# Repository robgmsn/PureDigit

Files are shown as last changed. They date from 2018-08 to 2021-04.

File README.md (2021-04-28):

# GMSN! Pure Digit
  
cc-by 4.0

Rob Spencer

[gmsn.co.uk](https://gmsn.co.uk)

[forum.gmsn.co.uk](https://forum.gmsn.co.uk)

Open Source Synth Designs.

DESIGN STATUS: Awaiting Testing - Ready for beta testing

Digit Updated to V2.0 28/4/21

RC filter added to DAC output.
Cap added to output opamp.
SD Card Reader added.

To do: Replace power so 5V comes from case power supply, inline with low noise techniques. May require complete redesign.

### Intro
This repo contains both the Library and Sketches for the GMSN! Pure Digit.

A small programmable utility module which accepts +/- 10V in,
does some digital processing, and outputs a +/-10V signal.

It has a 2 Channel 12bit ADC In, 12bit DAC Out, a 24
position rotary encoder with switch and a 7 segment LED display.

## To install the library

The library is installed via the normal Arduino Library management system.
  
1. From within the Arduino IDE, click on Sketch>Include Library>Manage Libraries...
  
2. Search for "GMSN" and click install.

### Sketches   
- [x] VCO
- [x] Noise
- [x] EmptySketch
- [x] RandomSequencer
- [ ] Clock Divider
- [ ] MicroTuner
- [x] BitCrusher
- [ ] Drums
- [ ] RhythmPlayer
- [ ] SwingMachine
- [ ] LFO
- [ ] StepLFO
- [x] DCLevel
- [ ] Module Testing Functions
- [ ] FrequencyCounter
- [ ] DCMeter

### Methods

encodeVal(int value) - Call this to increment or decrement a value with the rotary encoder.

displayLED(int digit, byte mode, bool dp) - The display has two modes:
                              1) Standard 0 - 9 digital digit.
                              2) Positional representation with 12 values. Where the knob is pointing!
                                 This uses the result of a modulo calculation so the value can be greater
                                 than 12 and it will keep rotating. It can't go less than zero though.

displayOff() - Turns the display off.

dacWrite(int value) - Write a value to the DAC. Yes, it's got a 20V P2P voltage!! :D
           0    =   +10V
           2048 =   0V
           4095 =   -10V

dacWriteCal(int value) - Write a value to the DAC, but using the calibration values. Use this when you need to ensure the output matches the module input, especially when processing audio or pitch CV.

adcRead(byte channel) - Read a 20V P2P from the DAC, channel 1 or 2. Voltages as above.

dontCalibrate() - If you don't actually need to use dacWriteCal(), then call dontCalibrate() before begin().

calibrate() - Some applications need the output to follow the output as closely as possible. If you have an audio signal coming in, you want the output to be the same. Due small differences in components, there will be both Gain Error and Offset Error that needs to be accounted for. This is a very simple routine which runs once everytime the module is flashed. The calibration values are then stored in EEPROM and used whenever dacWriteCal() is called.

getSwitchState() - This method returns the state of the switch, 1 for pressed, 0 for not pressed.

### How to calibrate

If the module hasn't been calibrated, it will run through a self calibration routine. You just need a single patch cable, no other modules or test kit required!

First of all the module will flash "8" a few times, before entering the calibration routine.

1) When it displays "1" patch from the output back into input 1.
2) Long Press the encoder.
3) Patch from output into input 2.
4) Long Press the encoder.

It will then count down to zero and flash. The module is now calibrated.

N.B. The calibration settings are stored in EEPROM, which is overwritten every time the module is flashed, therefor the calibration routing will run everytime the module is flashed.

### Example Sketch
```
// A random sequencer with variable delay

#include <Digit.h>                    //Include the Digit library

Digit digit;                          //Create a Digit called digit. This object now has the methods above available to it.

//Setup variables
int encPos = 1;                       //Just some variables for us to use in the code

void setup() {
 digit.begin();                       //Tell digit to configure its self.
}

void loop() {
   encPos = digit.encodeVal(encPos);  //Increment or decrement the varible encPos
   digit.displayLED(encPos, 2, 0);    //Display the value of encPos as a Positional Representation with no decimal point
   digit.dacWrite(random(4095));      //Output a random value between 0 and 4095, which is analogue +/- 10V
   delay(encPos);                     //Delay for encPos milliseconds.
}
```

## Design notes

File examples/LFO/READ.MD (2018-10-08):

LFO 
This code by Andy Cobley
Rate is controlled by CV1, Shape by CV2. The shape changes the duty cycle, for a Square wave this gives PWM, Triangle from +saw to triangle to -Saw. There others similarly.

Encoder position

0: Sine
1: Square
2: Triangle
3: Sine based on Triangle (can produce a nice output)

4,5,6,7 the same but slower cycles
Higher encoder positons give slower cycles still .
Loops at 19 and 0

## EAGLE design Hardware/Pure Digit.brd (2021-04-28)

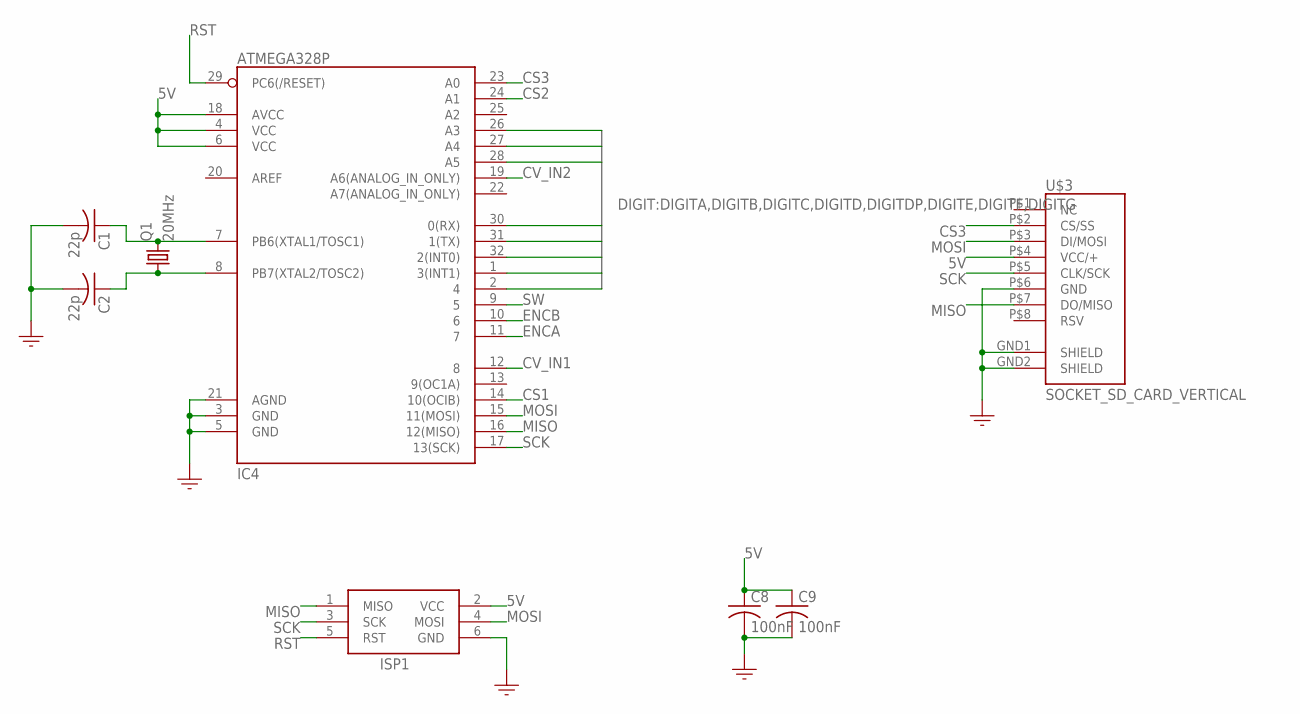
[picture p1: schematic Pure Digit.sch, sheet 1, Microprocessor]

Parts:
C1, C2: 22p; C0805
C8, C9: 100nF; C0805
IC4: ATMEGA328P; TQFP32-08
ISP1: HEADER2X3-6; AVRISP
Q1: 20MHz; SM49
U$3: SOCKET_SD_CARD_VERTICAL; PJS008U-3000

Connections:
5V: C8.1, C9.1, IC4.4 (VCC), IC4.6 (VCC), IC4.18 (AVCC), ISP1.2 (VCC), U$3.P$4 (VCC/+); also elsewhere on the board
CS1: IC4.14 (10(OCIB)); also elsewhere on the board
CS2: IC4.24 (A1); also elsewhere on the board
CS3: IC4.23 (A0), U$3.P$2 (CS/SS)
CV_IN1: IC4.12 (8); also elsewhere on the board
CV_IN2: IC4.19 (A6(ANALOG_IN_ONLY)); also elsewhere on the board
DIGITA: IC4.30 (0(RX)); also elsewhere on the board
DIGITB: IC4.28 (A5); also elsewhere on the board
DIGITC: IC4.27 (A4); also elsewhere on the board
DIGITD: IC4.26 (A3); also elsewhere on the board
DIGITDP: IC4.1 (3(INT1)); also elsewhere on the board
DIGITE: IC4.2 (4); also elsewhere on the board
DIGITF: IC4.32 (2(INT0)); also elsewhere on the board
DIGITG: IC4.31 (1(TX)); also elsewhere on the board
ENCA: IC4.11 (7); also elsewhere on the board
ENCB: IC4.10 (6); also elsewhere on the board
GND: C1.2, C2.2, C8.2, C9.2, IC4.3 (GND), IC4.5 (GND), IC4.21 (AGND), ISP1.6 (GND), U$3.GND1 (SHIELD), U$3.GND2 (SHIELD), U$3.P$6 (GND); also elsewhere on the board
MISO: IC4.16 (12(MISO)), ISP1.1 (MISO), U$3.P$7 (DO/MISO); also elsewhere on the board
MOSI: IC4.15 (11(MOSI)), ISP1.4 (MOSI), U$3.P$3 (DI/MOSI); also elsewhere on the board
unnamed: C1.1, IC4.7 (PB6(XTAL1/TOSC1)), Q1.2
unnamed: C2.1, IC4.8 (PB7(XTAL2/TOSC2)), Q1.1
RST: IC4.29 (PC6(/RESET)), ISP1.5 (RST)
SCK: IC4.17 (13(SCK)), ISP1.3 (SCK), U$3.P$5 (CLK/SCK); also elsewhere on the board
SW: IC4.9 (5); also elsewhere on the board

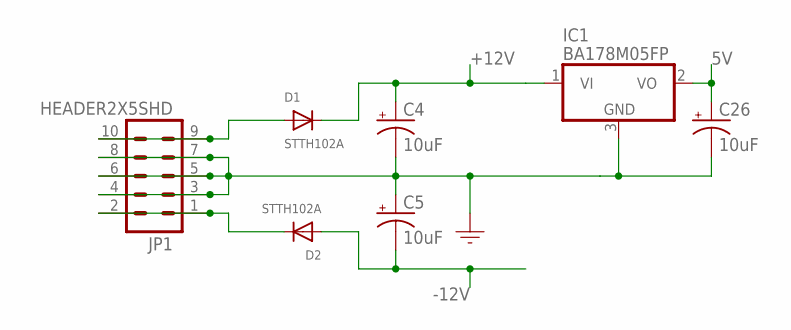
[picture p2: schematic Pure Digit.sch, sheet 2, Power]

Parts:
C4, C5, C26: 10uF; 153CLV-0505
D1, D2: STTH102A; SMADIODE
IC1: BA178M05FP; TO252
JP1: HEADER2X5SHD; 2X5-SHROUDED

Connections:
5V: C26.+, IC1.2 (VO); also elsewhere on the board
+12V: C4.+, D1.C, IC1.1 (VI); also elsewhere on the board
-12V: C5.-, D2.A; also elsewhere on the board
GND: C4.-, C5.+, C26.-, IC1.3 (GND), JP1.3, JP1.4, JP1.5, JP1.6, JP1.7, JP1.8; also elsewhere on the board
unnamed: D1.A, JP1.9, JP1.10
unnamed: D2.C, JP1.1, JP1.2

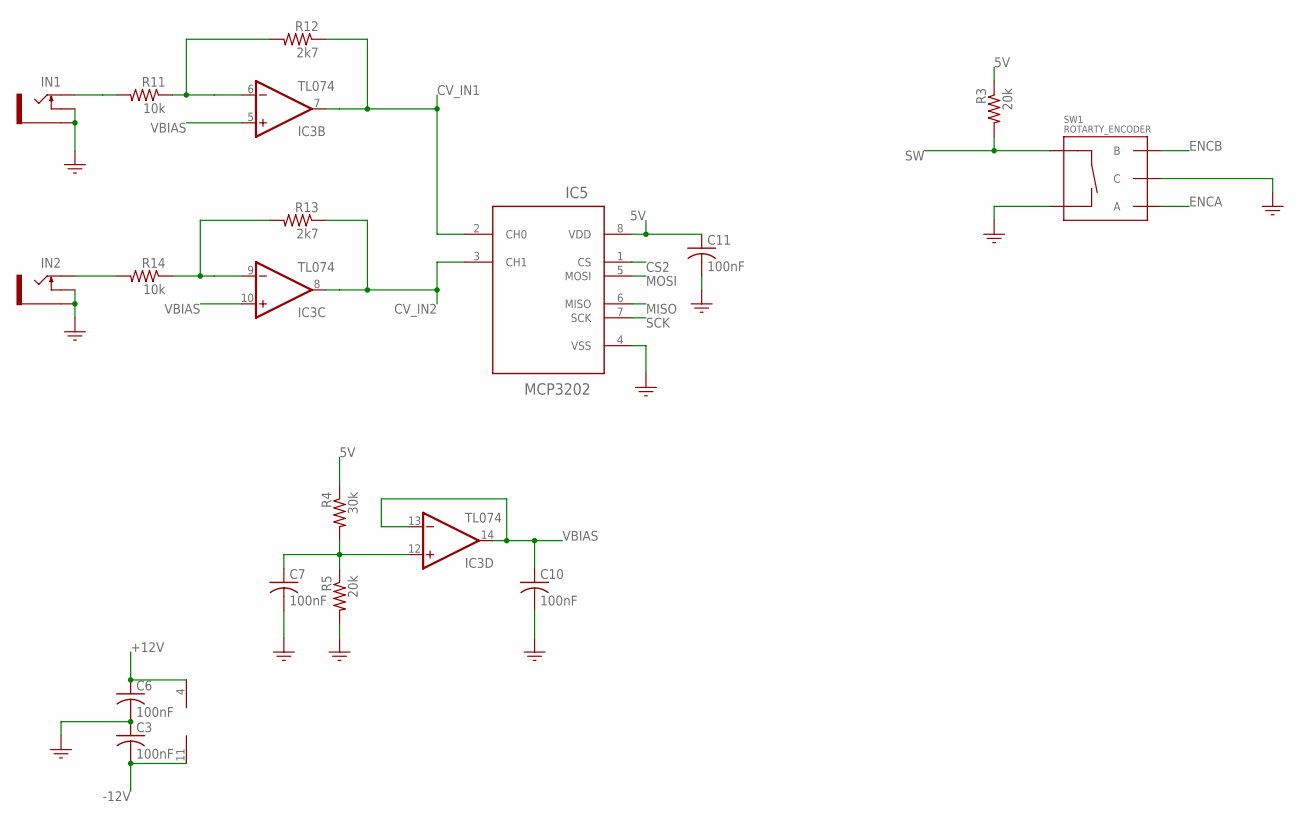
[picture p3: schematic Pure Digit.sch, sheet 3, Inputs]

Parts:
C3, C6, C7, C10, C11: 100nF; C0805
IC3: TL074; SO14
IC5: MCP3202; SOIC--8
IN1, IN2: PJ301M-12
R3, R5: 20k; R0805
R4: 30k; R0805
R11, R14: 10k; R0805
R12, R13: 2k7; R0805
SW1: ROTARTY_ENCODER; ROTARY_ENC_PLAIN

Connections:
5V: C11.1, IC5.8 (VDD), R3.1, R4.1; also elsewhere on the board
+12V: C6.1, IC3.4 (V+); also elsewhere on the board
-12V: C3.2, IC3.11 (V-); also elsewhere on the board
CS2: IC5.1 (CS); also elsewhere on the board
CV_IN1: IC3.7 (OUT), IC5.2 (CH0), R12.1; also elsewhere on the board
CV_IN2: IC3.8 (OUT), IC5.3 (CH1), R13.1; also elsewhere on the board
ENCA: SW1.A; also elsewhere on the board
ENCB: SW1.B; also elsewhere on the board
GND: C3.1, C6.2, C7.2, C10.2, C11.2, IC5.4 (VSS), IN1.GND (SLEEVE), IN1.NORM (SWITCH), IN2.GND (SLEEVE), IN2.NORM (SWITCH), R5.2, SW1.C, SW1.SW-; also elsewhere on the board
MISO: IC5.6 (MISO); also elsewhere on the board
MOSI: IC5.5 (MOSI); also elsewhere on the board
unnamed: IN1.TIP, R11.2
unnamed: IN2.TIP, R14.2
unnamed: C7.1, IC3.12 (+IN), R4.2, R5.1
unnamed: IC3.6 (-IN), R11.1, R12.2
unnamed: IC3.9 (-IN), R13.2, R14.1
SCK: IC5.7 (SCK); also elsewhere on the board
SW: R3.2, SW1.SW+; also elsewhere on the board
VBIAS: C10.1, IC3.5 (+IN), IC3.10 (+IN), IC3.13 (-IN), IC3.14 (OUT)

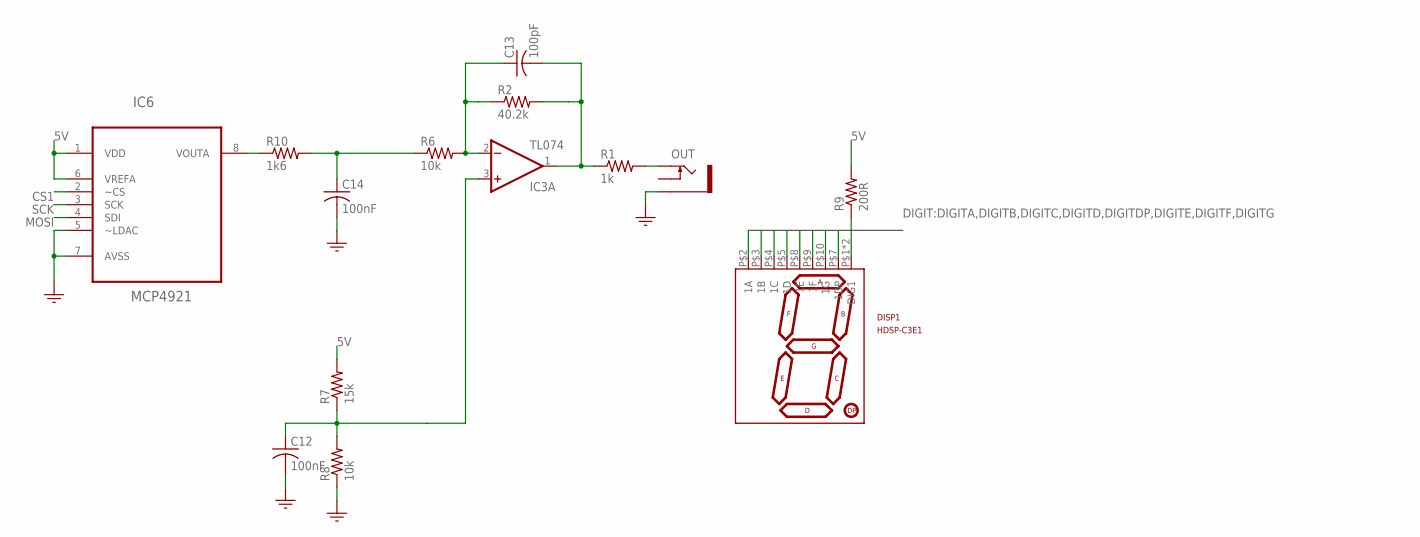
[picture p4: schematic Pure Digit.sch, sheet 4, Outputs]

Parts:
C12, C14: 100nF; C0805
C13: 100pF; C0805
DISP1: HDSP-C3E1; 7-SEGMENT-1DIGIT
IC3: TL074; SO14
IC6: MCP4921; SOIC8
OUT: PJ301M-12
R1: 1k; R0805
R2: 40.2k; R0805
R6, R8: 10k; R0805
R7: 15k; R0805
R9: 200R; R0805
R10: 1k6; R0805

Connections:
5V: IC6.1 (VDD), IC6.6 (VREFA), R7.2, R9.2; also elsewhere on the board
CS1: IC6.2 (~CS); also elsewhere on the board
DIGITA: DISP1.P$2 (1A); also elsewhere on the board
DIGITB: DISP1.P$3 (1B); also elsewhere on the board
DIGITC: DISP1.P$4 (1C); also elsewhere on the board
DIGITD: DISP1.P$5 (1D); also elsewhere on the board
DIGITDP: DISP1.P$7 (1DP); also elsewhere on the board
DIGITE: DISP1.P$8 (1E); also elsewhere on the board
DIGITF: DISP1.P$9 (1F); also elsewhere on the board
DIGITG: DISP1.P$10 (1G); also elsewhere on the board
GND: C12.2, C14.2, IC6.5 (~LDAC), IC6.7 (AVSS), OUT.GND (SLEEVE), R8.1; also elsewhere on the board
MOSI: IC6.4 (SDI); also elsewhere on the board
unnamed: C12.1, IC3.3 (+IN), R7.1, R8.2
unnamed: C13.2, IC3.1 (OUT), R1.1, R2.2
unnamed: OUT.TIP, R1.2
unnamed: C14.1, R6.1, R10.2
unnamed: C13.1, IC3.2 (-IN), R2.1, R6.2
unnamed: DISP1.P$1 (DIG1), DISP1.P$6 (DIG1), R9.1
unnamed: IC6.8 (VOUTA), R10.1
SCK: IC6.3 (SCK); also elsewhere on the board

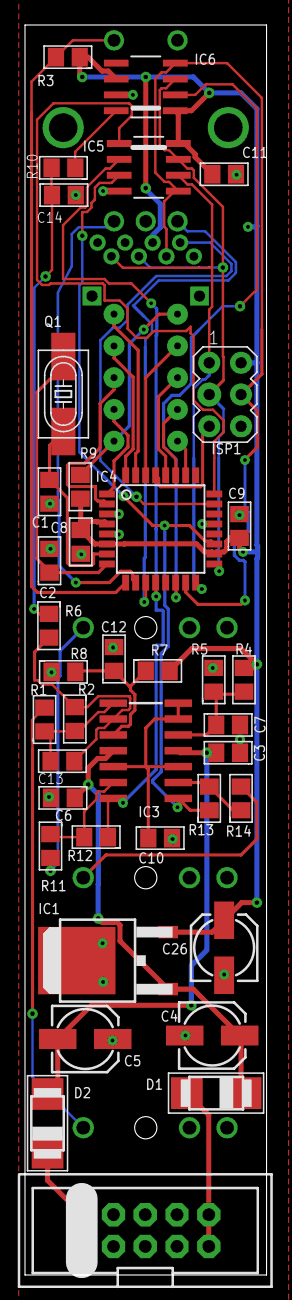
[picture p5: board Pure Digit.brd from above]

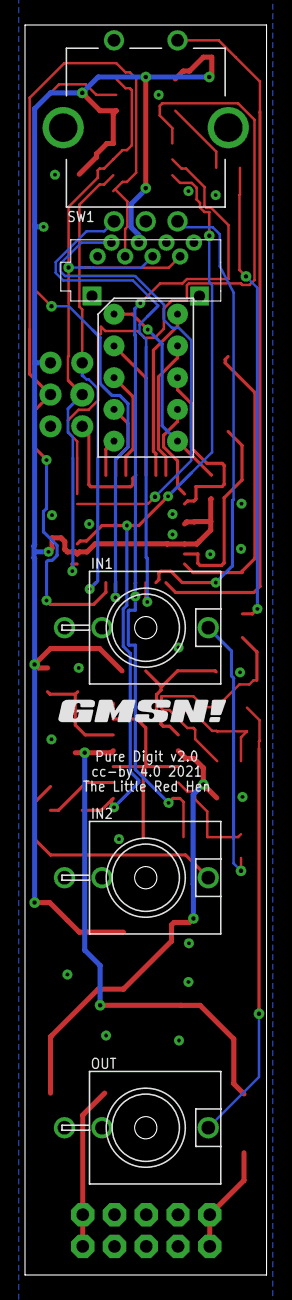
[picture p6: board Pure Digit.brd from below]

Board: 2 copper layers, 19.3 x 100.0 mm, 46 parts (7 on the bottom side), 41 nets.

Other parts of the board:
U$1: GMSN!_LOGO

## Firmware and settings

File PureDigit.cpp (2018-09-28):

/*
  GMSN! Pure Digit v1
  28th July 2018
  cc-by 4.0
  Rob Spencer
  gmsn.co.uk
  forum.gmsn.co.uk
  Open Source Synth Designs.

  This library is used to control the GMSN! Pure Digit. A small programmable utility module which accepts +/- 10V in,
  does some digital processing, and outputs a +/-10V signal. It has a 2 Channel 12bit ADC In, 12bit DAC Out, a 24
  position rotary encoder with switch and a 7 segment LED display.

  Examples include:   Noise, Clock Divider, Micro Tuner, Bit Crusher, Drums, Rhythm Player, Swing Machine, LFO, Step LFO,
  DC Level, Module Testing Functions, Frequency Counter, DC Meter

  See README.md for details on the available methods and calibrate routine.

  Example Sketch:

  <code>
  #include <PureDigit.h>

  PureDigit digit;

  //Setup variables
  int encPos = 1;
  int cvIn, cvOut;


  void setup() {

   digit.begin();

  }

  void loop() {

     encPos = digit.encodeVal(encPos);  //Increment or decrement the varible encPos
     digit.displayLED(encPos, 2, 0);    //Display the value of encPos as a Positional Representation with no decimal point
     digit.dacWrite(random(4095));      //Output a random value between 0 and 4095, which is analogue +/- 10V
     delay(encPos);                     //Delay for encPos milliseconds.

  }
  </code>
*/

#include <Arduino.h>
#include <SPI.h>
#include "PureDigit.h"
#include <EEPROM.h>

//Setup Digit
#define digitA 0 //30
#define digitB A5 //28
#define digitC A4 //27
#define digitD A3 //26
#define digitE 4 //2
#define digitF 2 //32
#define digitG 1 //31
#define digitDP 3 //1

//Setup Encoder
//SW
#define sw 5 //9

//Encoder
#define encA 7 //11
#define encB 6 //10


//Setup SPI Bus
#define csADC A1 //9 //13 or 24
#define csDAC 10 //14

boolean doCalibrate=true;

PureDigit::PureDigit() {

        int encAVal, encALast, encBVal = 0;
        float Ge1 = 0;
        float Ge2 = 0;
        float Oe1 = 0;
        float Oe2 = 0;
}

void PureDigit::dontCalibrate(){
     doCalibrate=false;
}

void PureDigit::begin() {

        //Setup Digit Pins
        pinMode(digitA, OUTPUT);
        pinMode(digitB, OUTPUT);
        pinMode(digitC, OUTPUT);
        pinMode(digitD, OUTPUT);
        pinMode(digitE, OUTPUT);
        pinMode(digitF, OUTPUT);
        pinMode(digitG, OUTPUT);
        pinMode(digitDP, OUTPUT);

        digitalWrite(digitA, HIGH);
        digitalWrite(digitB, HIGH);
        digitalWrite(digitC, HIGH);
        digitalWrite(digitD, HIGH);
        digitalWrite(digitE, HIGH);
        digitalWrite(digitF, HIGH);
        digitalWrite(digitG, HIGH);
        digitalWrite(digitDP, HIGH);

        //Setup Encoder Pins
        pinMode(sw, INPUT);
        pinMode(encA, INPUT);
        pinMode(encB, INPUT);
        digitalWrite(encA, HIGH);
        digitalWrite(encB, HIGH);

        //Setup DAC/ADC Pins
        pinMode(csADC, OUTPUT);
        pinMode(csDAC, OUTPUT);

        digitalWrite(csADC, HIGH);
        digitalWrite(csDAC, HIGH);
        SPI.begin();

        byte calFlag = EEPROM.read(0);
        if (doCalibrate==true){
        if (calFlag == 0) {
                EEPROM.get(1, Ge1);
                EEPROM.get(5, Ge2);
                EEPROM.get(9, Oe1);
                EEPROM.get(13, Oe2);
        } else {
                for (int x = 0; x < 10; x++) {
                        displayLED(8, 1, 0);
                        delay(200);
                        displayOff();
                        delay(100);
                }
                calibrate();
        }
        }else{
            Oe1=0.0;
            Ge1=1.0;
        }
}

int PureDigit::encodeVal(int val) {
        encAVal = digitalRead(encA);
        encBVal = digitalRead(encB);
        if (encAVal != encALast) {
                if (encAVal == encBVal) {
                        val--;
                } else {
                        val++;
                }
                encALast = encAVal;
        }
        return val;
}

bool PureDigit::getSwitchState() {
        bool swState = !digitalRead(sw);
        return swState;
}

void PureDigit::displayOff() {
        digitalWrite(digitA, HIGH);
        digitalWrite(digitB, HIGH);
        digitalWrite(digitC, HIGH);
        digitalWrite(digitD, HIGH);
        digitalWrite(digitE, HIGH);
        digitalWrite(digitF, HIGH);
        digitalWrite(digitG, HIGH);
}

void PureDigit::displayLED(int digit, byte mode, bool dp) {
        if (dp == 1) {
                digitalWrite(digitDP, LOW);
        } else {
                digitalWrite(digitDP, HIGH);
        }
        if (mode == 1) {
                switch (digit) {
                case 0:
                        digitalWrite(digitA, LOW);
                        digitalWrite(digitB, HIGH);
                        digitalWrite(digitC, LOW);
                        digitalWrite(digitD, LOW);
                        digitalWrite(digitE, LOW);
                        digitalWrite(digitF, LOW);
                        digitalWrite(digitG, LOW);
                        break;
                case 1:
                        digitalWrite(digitA, HIGH);
                        digitalWrite(digitB, HIGH);
                        digitalWrite(digitC, HIGH);
                        digitalWrite(digitD, HIGH);
                        digitalWrite(digitE, LOW);
                        digitalWrite(digitF, LOW);
                        digitalWrite(digitG, HIGH);
                        break;
                case 2:
                        digitalWrite(digitA, HIGH);
                        digitalWrite(digitB, LOW);
                        digitalWrite(digitC, LOW);
                        digitalWrite(digitD, LOW);
                        digitalWrite(digitE, HIGH);
                        digitalWrite(digitF, LOW);
                        digitalWrite(digitG, LOW);
                        break;
                case 3:
                        digitalWrite(digitA, HIGH);
                        digitalWrite(digitB, LOW);
                        digitalWrite(digitC, HIGH);
                        digitalWrite(digitD, LOW);
                        digitalWrite(digitE, LOW);
                        digitalWrite(digitF, LOW);
                        digitalWrite(digitG, LOW);
                        break;
                case 4:
                        digitalWrite(digitA, LOW);
                        digitalWrite(digitB, LOW);
                        digitalWrite(digitC, HIGH);
                        digitalWrite(digitD, HIGH);
                        digitalWrite(digitE, LOW);
                        digitalWrite(digitF, LOW);
                        digitalWrite(digitG, HIGH);
                        break;
                case 5:
                        digitalWrite(digitA, LOW);
                        digitalWrite(digitB, LOW);
                        digitalWrite(digitC, HIGH);
                        digitalWrite(digitD, LOW);
                        digitalWrite(digitE, LOW);
                        digitalWrite(digitF, HIGH);
                        digitalWrite(digitG, LOW);
                        break;
                case 6:
                        digitalWrite(digitA, LOW);
                        digitalWrite(digitB, LOW);
                        digitalWrite(digitC, LOW);
                        digitalWrite(digitD, LOW);
                        digitalWrite(digitE, LOW);
                        digitalWrite(digitF, HIGH);
                        digitalWrite(digitG, HIGH);
                        break;
                case 7:
                        digitalWrite(digitA, HIGH);
                        digitalWrite(digitB, HIGH);
                        digitalWrite(digitC, HIGH);
                        digitalWrite(digitD, HIGH);
                        digitalWrite(digitE, LOW);
                        digitalWrite(digitG, LOW);
                        digitalWrite(digitF, LOW);
                        break;
                case 8:
                        digitalWrite(digitA, LOW);
                        digitalWrite(digitB, LOW);
                        digitalWrite(digitC, LOW);
                        digitalWrite(digitD, LOW);
                        digitalWrite(digitE, LOW);
                        digitalWrite(digitF, LOW);
                        digitalWrite(digitG, LOW);
                        break;
                case 9:
                        digitalWrite(digitA, LOW);
                        digitalWrite(digitB, LOW);
                        digitalWrite(digitC, HIGH);
                        digitalWrite(digitD, HIGH);
                        digitalWrite(digitE, LOW);
                        digitalWrite(digitF, LOW);
                        digitalWrite(digitG, LOW);
                        break;
                }
        } else if (mode = 2) {

                digit = digit % 12;

                switch (digit) {
                case 0:
                        digitalWrite(digitA, HIGH);
                        digitalWrite(digitB, HIGH);
                        digitalWrite(digitC, HIGH);
                        digitalWrite(digitD, LOW);
                        digitalWrite(digitE, HIGH);
                        digitalWrite(digitF, HIGH);
                        digitalWrite(digitG, HIGH);
                        break;
                case 1:
                        digitalWrite(digitA, HIGH);
                        digitalWrite(digitB, HIGH);
                        digitalWrite(digitC, LOW);
                        digitalWrite(digitD, LOW);
                        digitalWrite(digitE, HIGH);
                        digitalWrite(digitF, HIGH);
                        digitalWrite(digitG, HIGH);
                        break;
                case 2:
                        digitalWrite(digitA, HIGH);
                        digitalWrite(digitB, HIGH);
                        digitalWrite(digitC, LOW);
                        digitalWrite(digitD, HIGH);
                        digitalWrite(digitE, HIGH);
                        digitalWrite(digitF, HIGH);
                        digitalWrite(digitG, HIGH);
                        break;
                case 3:
                        digitalWrite(digitA, LOW);
                        digitalWrite(digitB, HIGH);
                        digitalWrite(digitC, LOW);
                        digitalWrite(digitD, HIGH);
                        digitalWrite(digitE, HIGH);
                        digitalWrite(digitF, HIGH);
                        digitalWrite(digitG, HIGH);
                        break;
                case 4:
                        digitalWrite(digitA, LOW);
                        digitalWrite(digitB, HIGH);
                        digitalWrite(digitC, HIGH);
                        digitalWrite(digitD, HIGH);
                        digitalWrite(digitE, HIGH);
                        digitalWrite(digitF, HIGH);
                        digitalWrite(digitG, HIGH);
                        break;
                case 5:
                        digitalWrite(digitA, LOW);
                        digitalWrite(digitB, HIGH);
                        digitalWrite(digitC, HIGH);
                        digitalWrite(digitD, HIGH);
                        digitalWrite(digitE, HIGH);
                        digitalWrite(digitF, HIGH);
                        digitalWrite(digitG, LOW);
                        break;
                case 6:
                        digitalWrite(digitA, HIGH);
                        digitalWrite(digitB, HIGH);
                        digitalWrite(digitC, HIGH);
                        digitalWrite(digitD, HIGH);
                        digitalWrite(digitE, HIGH);
                        digitalWrite(digitF, HIGH);
                        digitalWrite(digitG, LOW);
                        break;
                case 7:
                        digitalWrite(digitA, HIGH);
                        digitalWrite(digitB, HIGH);
                        digitalWrite(digitC, HIGH);
                        digitalWrite(digitD, HIGH);
                        digitalWrite(digitE, HIGH);
                        digitalWrite(digitF, LOW);
                        digitalWrite(digitG, LOW);
                        break;
                case 8:
                        digitalWrite(digitA, HIGH);
                        digitalWrite(digitB, HIGH);
                        digitalWrite(digitC, HIGH);
                        digitalWrite(digitD, HIGH);
                        digitalWrite(digitE, HIGH);
                        digitalWrite(digitF, LOW);
                        digitalWrite(digitG, HIGH);
                        break;
                case 9:
                        digitalWrite(digitA, HIGH);
                        digitalWrite(digitB, HIGH);
                        digitalWrite(digitC, HIGH);
                        digitalWrite(digitD, HIGH);
                        digitalWrite(digitE, LOW);
                        digitalWrite(digitF, LOW);
                        digitalWrite(digitG, HIGH);
                        break;
                case 10:
                        digitalWrite(digitA, HIGH);
                        digitalWrite(digitB, HIGH);
                        digitalWrite(digitC, HIGH);
                        digitalWrite(digitD, HIGH);
                        digitalWrite(digitE, LOW);
                        digitalWrite(digitF, HIGH);
                        digitalWrite(digitG, HIGH);
                        break;
                case 11:
                        digitalWrite(digitA, HIGH);
                        digitalWrite(digitB, HIGH);
                        digitalWrite(digitC, HIGH);
                        digitalWrite(digitD, LOW);
                        digitalWrite(digitE, LOW);
                        digitalWrite(digitF, HIGH);
                        digitalWrite(digitG, HIGH);
                        break;
                }
        }
}

void PureDigit::dacWrite(int value) {
        digitalWrite(csDAC, LOW);
        constrain(value, 0, 4095);
        value = value + 12288;
        SPI.transfer16(value);
        digitalWrite(csDAC, HIGH);
}

void PureDigit::dacWriteCal(int value) {
        value = float(value);
        value = (value - Oe1) / Ge1;
        value = constrain(value, 0, 4095);
        dacWrite(value);
}

int PureDigit::adcRead(byte channel) {

        int commandbits = 40960;
        if (channel == 2) {
                commandbits = commandbits + 16384;
        }
        unsigned int result;
        digitalWrite(csADC, LOW);
        SPI.transfer(1);
        result = SPI.transfer16(commandbits);
        result = result & 4095;
        digitalWrite(csADC, HIGH);
        return result;
}

void PureDigit::calibrate(){
        int n1, n2, i;
        int stage = 1;
        bool swState, lastSwState;

//loop
        while (stage < 6) {
                switch (stage) {
                case 1:
                        //Connect Output to Input 1 & Wait
                        flashLED(1, 1, 500);
                        break;

                case 2:
                        //Output 512 and read ADC
                        dacWrite(512);
                        delay(50);
                        n1 = adcRead(1);
                        delay(50);

                        //Output 3584 and read ADC
                        dacWrite(3584);
                        delay(50);
                        n2 = adcRead(1);

                        //Calculate Ge1 = (n2 - n1)/(3584 - 512)
                        Ge1 = (n2 - n1) / (3584.0 - 512.0);

                        //Calculate Oe1 = n1 - (Ge * 512)
                        Oe1 = n1 - (Ge1 * 512.0);

                        flashLED(1, 10, 50);
                        stage = 3;
                        break;

                case 3:
                        //Connect Output to Input 2 & Wait
                        flashLED(2, 1, 500);
                        break;

                case 4:
                        //Output 512 and read ADC
                        dacWrite(512);
                        delay(50);
                        n1 = adcRead(2);
                        delay(50);

                        //Output 3584 and read ADC
                        dacWrite(3584);
                        delay(50);
                        n2 = adcRead(2);

                        //Calculate Ge1 = (n2 - n1)/(3584 - 512)
                        Ge2 = (n2 - n1) / (3584.0 - 512.0);

                        //Calculate Oe1 = n1 - (Ge * 512)
                        Oe2 = n1 - (Ge2 * 512.0);

                        flashLED(2, 10, 50);
                        stage = 5;
                        break;

                case 5:
                        flashLED(9, 20, 5);
                        flashLED(8, 20, 5);
                        flashLED(7, 20, 5);
                        flashLED(6, 20, 5);
                        flashLED(5, 10, 5);
                        flashLED(4, 20, 5);
                        flashLED(3, 20, 5);
                        flashLED(2, 20, 5);
                        flashLED(1, 20, 5);
                        displayLED(8, 1, 0);
                        delay(200);
                        displayOff();
                        delay(100);
                        displayLED(8, 1, 0);
                        delay(200);
                        displayOff();
                        delay(100);
                        displayLED(8, 1, 0);
                        delay(200);
                        displayOff();
                        delay(100);
                        displayLED(8, 1, 0);
                        delay(200);
                        displayOff();

                        //Store Ge1, Ge2, Oe1 and Oe2
                        EEPROM.put(1, Ge1);
                        EEPROM.put(5, Ge2);
                        EEPROM.put(9, Oe1);
                        EEPROM.put(13, Oe2);
                        EEPROM.write(0, 0);
                        delay(100);
                        displayLED(8, 1, 0);
                        delay(200);
                        displayOff();
                        delay(100);
                        stage = 6;
                        break;


                }

//Poll Button

                swState = getSwitchState();
                if (swState == 1 && swState != lastSwState) {
                        switch (stage) {
                        case 1:
                                stage = 2;
                                break;
                        case 3:
                                stage = 4;
                                break;
                        case 6:
                                stage = 7;
                                break;
                        case 8:
                                stage = 9;
                                break;
                        }

                        lastSwState = 1;
                } else {
                        lastSwState = 0;
                }
        }
}

void PureDigit::flashLED(int number, int repeats, int delays) {
        int i = 0;
        while ( i < repeats) {
                displayLED(number, 1, 1);
                delay(delays);
                displayLED(number, 1, 0);
                delay(delays);
                i++;
        }
}

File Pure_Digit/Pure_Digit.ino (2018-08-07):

/*
  GMSN! Pure Digit v0.1
  28th July 2018
  cc-by 4.0
  Rob Spencer

  Write various codes
  Enable EEPROM
  Trimming Inputs and Outputs and test for variation between modules

  Noise
  Clk Divider
  Micro Tuner
  Bit Crusher
  Drums
  Rhythm Player
  Swing Machine
  LFO
  Step LFO
  DC Level
  Module Testing Functions
  Frequency Counter
  DC Meter

*/

#include <Digit.h>

Digit digit;

//Setup variables
int encPos = 1;
int cvIn, cvOut;


void setup() {

 digit.begin();

}

void loop() {

   encPos = digit.encodeVal(encPos);
   digit.displayLED(encPos, 1, 0);
   digit.dacWrite(random(4095));
   if (encPos < 1) {
    encPos = 1;
   }
   delay(encPos);

}

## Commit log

2018-08-15 Self Calibration added
2018-09-04 added Don't Calibrate methods
2018-10-08 Added support for digits 10-19 and encoder loop at <0 and >19
2018-10-31 Updated Install instructions
    Library now available via the Arduino Library management system
2021-04-25 Digit 1.1
    Digit Updated to V1.1 25/4/21
    RC filter added to DAC output.
    Cap added to output opamp.
    To do: Replace power so 5V comes from case power supply, inline with low noise techniques. May require complete redesign.
    To do: Read from SD Card.
    [Pure Digit Panel.brd, Pure Digit.brd, Pure Digit.sch]
2021-04-28 Digit 2.0
    Digit Updated to V2.0 28/4/21
    SD Card Reader added.
    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
    [Pure Digit Panel.brd, Pure Digit.brd, Pure Digit.sch]

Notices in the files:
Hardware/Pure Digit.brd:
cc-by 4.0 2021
